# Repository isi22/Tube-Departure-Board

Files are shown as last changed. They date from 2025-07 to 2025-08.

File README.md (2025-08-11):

# 🚇 Tube Departure Board for Raspberry Pi

<!--- Start of badges -->
<!-- Badges: python,raspberrypi,api,3d_printing,electronics,tfl,fusion360 -->

<p align="left">

 
 
 
 
 
 
</p>
<!--- End of badges -->

<!--- Blurb
Recreate the iconic London Underground departure board with a Raspberry Pi! This Python-based application fetches live train data from the Transport for London (TfL) Unified API and displays it in real-time on a compact OLED screen, designed to mimic the classic dot-matrix look.
-->

<!--- Start of Thumbnail-->
<!--- src="Images/thumbnail.png" -->
<!--- End of Thumbnail-->

<div style="text-align:center;">
    <img src="Images/banner.jpg" alt="Miniature Tube Departure Board"">
</div>

Recreate the iconic London Underground departure board with a Raspberry Pi! This Python-based application fetches live train data from the Transport for London (TfL) Unified API and displays it in real-time on a compact OLED screen, designed to mimic the classic dot-matrix look. 

### Table of Contents

**[✨ Features](#-features) <br> 
[📋 Prerequisites](#-prerequisites) <br>
[🔌 Raspberry Pi Setup](#-raspberry-pi-setup) <br>
[🔧 Hardware Assembly and Wiring](#-hardware-assembly-and-wiring) <br>
[💻 Software Installation](#-software-installation) <br>
[🙏 Credits & Inspiration](#-credits--inspiration)**

<br>

## ✨ Features

- **Live London Underground Data:** Fetches real-time Tube arrival predictions for configurable stations and lines.

- **Dot-Matrix Aesthetics:** Utilises a [Dot Matrix Typeface](https://github.com/DanielHartUK/Dot-Matrix-Typeface) to give your display an authentic departure board feel.

- **Compact Display:** Designed for an SSD1322 OLED display on Raspberry Pi.

- **Dual Line Toggle:** Switch between two sets of Tube lines/directions using a physical toggle switch.

- **Smart Power Management:** Includes Raspberry Pi temperature monitoring to prevent overheating.

- **Multi-threaded Architecture:** Uses separate threads for API fetching and display rendering to ensure smooth, responsive updates.

- **Custom 3D-Printed Case:** Design files provided for a miniature Tube departure board enclosure.

## 📋 Prerequisites

To build your London Underground Departure Board, you'll need the following:

- **Raspberry Pi:** Any model capable of running Raspberry Pi OS. I personally used a [Pi Zero WH](https://thepihut.com/products/raspberry-pi-zero-wh-with-pre-soldered-header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).

- **Micro SD card:** For installing the Raspberry Pi OS.

- **Internet Connection:** For the Raspberry Pi to access the TfL API.

- **OLED Display:** An [SSD1322-based OLED display module](https://www.ebay.co.uk/itm/265720175865) connected via SPI.

- **Toggle Switch (Optional but Recommended):** A [mini toggle switch](https://www.amazon.co.uk/dp/B077D9FRGL?ref=ppx_pop_mob_ap_share) connected to a GPIO pin on your Raspberry Pi to switch between the two line configurations (e.g. westbound and eastbound).

- **Transport for London (TfL) API Key:** Tube arrival data is fetched from the [Transport for London Unified API](https://api.tfl.gov.uk/).

- **Access to a 3D printer:** STL files for the custom case, designed to resemble a miniature tube departure board, are provided within this repository.

- **8x [5mmx2mm magnets](https://www.amazon.co.uk/dp/B09H2W3TQZ?ref=ppx_pop_mob_ap_share):** For mounting the miniature departure board.

- **4x M2.6x8mm self tapping screws:** To secure the display and Raspberry Pi to the case.

- **2 x M2.6x6mm self tapping screws:** For closing the case with the back cover.

- **Superglue:** For assembling some of the 3D-printed parts and securing the magnets.

- **Wires and soldering equipment:** For connecting the display and switch to your Raspberry Pi.

## 🔌 Raspberry Pi Setup

These steps prepare your Raspberry Pi's operating system for the project.

### 1. Flash Raspberry Pi OS

- Download the [Raspberry Pi Imager](https://www.raspberrypi.com/software/) for your computer
- Use the Imager to flash Raspberry Pi OS onto your Micro SD card with the following OS customisation settings:
  - **Enable SSH** with password authentication (under the 'Services' tab). This is essential for connecting to your Pi remotely.
  - **Set a username and password.** Make a note of these; you'll need them for SSH access.
  - **Configure wireless LAN.** Add your SSID (Wi-Fi network name) and password.
  - **Set up the locale settings** with the `Europe/London` timezone.
- Insert the prepared SD card into your Raspberry Pi.

### 2. Connect to your Raspberry Pi

- The Raspberry Pi receives its power through its Micro USB Power port. Connect a standard 5V power supply to this port. *Note: On the Pi Zero WH, this is typically the port closest to the end of the board, distinct from any data-only USB ports.*

- Find your Pi's IP address (e.g., from your router's connected devices list) and connect via SSH from your computer:

    ```
    ssh <your_username>@<your_pi_ip_address>
    # Use the username and password you set in the Imager.
    ```

### 3. Enable SPI interface:

For your SSD1322 OLED, you'll need to enable the SPI interface on your Raspberry Pi.

- Open the Raspberry Pi Configuration tool:

    ```
    sudo raspi-config
    ```
- Navigate to `Interface Options` -> `SPI` -> `Yes` to enable it.

- Select `Finish` and reboot your Pi if prompted.

## 🔧 Hardware Assembly and Wiring

This section guides you through preparing the 3D-printed case and connecting your components.

### **1. Wiring:**

The SSD1322 OLED display is wired to the Raspberry Pi by following the comprehensive instructions found in [Chris Crocker-White's UK national rail departure display](https://github.com/chrisys/train-departure-display/blob/main/docs/02-connecting-the-display-to-the-pi.md).

Additionally, a toggle switch has been integrated into this project. This switch enables the display to cycle between different sets of arrival information (for example, distinguishing between eastbound and westbound trains, or various platforms). It is set up in a pull-down configuration, as shown in the provided diagram:

- Connect the centre terminal of the switch to a 3.3V power pin on the Raspberry Pi (e.g., physical pin 17).

- Connect one of the outer terminals of the switch to a Raspberry Pi GPIO pin (e.g. GPIO17, physical pin 11).

- Connect a ~10k Ohm resistor between the Raspberry Pi GPIO pin and a ground pin on the Raspberry Pi. This resistor acts as a pull-down, ensuring the GPIO pin is held low when the switch is open.

      +--------------- (Raspberry Pi 3.3V Power Pin)
      |
      |
      |   +--------------------+
      |   |                    |
      |   |      (Switch)      |
      |   |                    |
      |   +--------------------+
      |             |          |
      |        (Centre Pin) (Outer Pin)
      |             |          |
      +-------------+          |
                               |
                               +------------ Raspberry Pi GPIO Pin
                               |
                               |
                        [ 10kΩ Resistor ]
                               |
                               |
                               | 
                   Raspberry Pi Ground Pin

### **2. 3D Print the Case:**

3D print the [STL files](3D_print_files) provided in this repository. I printed the parts using black PLA filament on an Ender 3 printer.

To give a quick overview, the 3D-printed case consists of the following parts, designed to assemble into a compact and functional departure board:

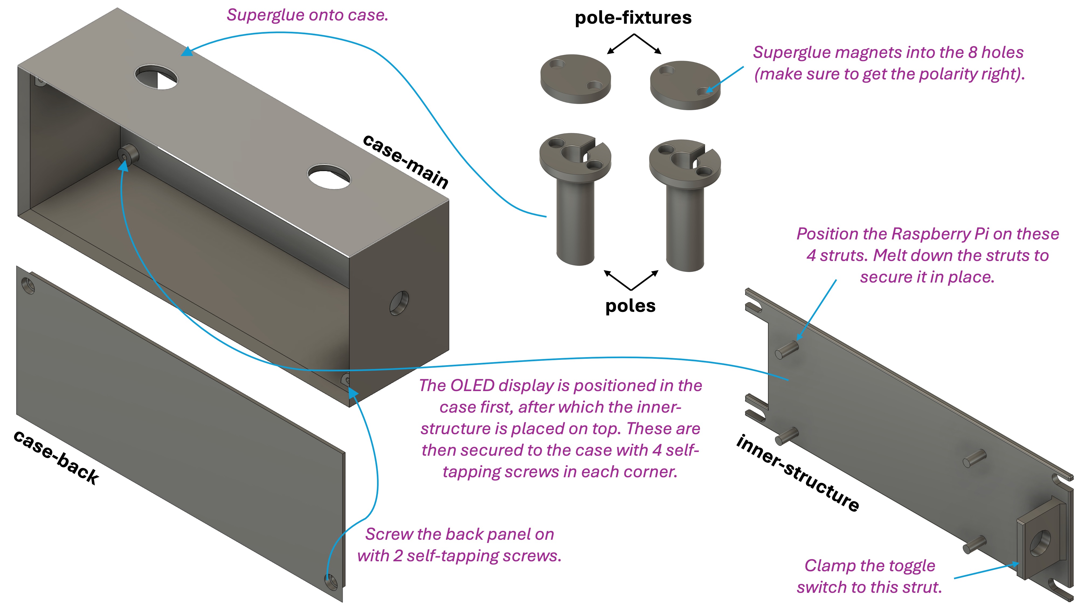
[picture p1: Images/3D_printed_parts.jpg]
3D printed parts illustration


- **Case-main:** The primary rectangular enclosure featuring a cutout at the front for securely fitting the OLED display. Its open rear is designed to be covered by the `case-back` panel.

- **Case-back:** A flat panel that forms the rear closure of the `case-main`, attaching securely with self-tapping screws.

- **Pole (x2):** Two hollow, elliptical posts designed to be superglued to the top of the `case-main`. They align with an elliptical opening on the `case-main`'s top surface, allowing the Raspberry Pi's Micro USB power cable to pass through them. The top of each pole is designed to house two 5mm diameter magnets for mounting the assembled board.

- **Pole-fixture (x2):** Two flat, elliptical parts that are intended to be permanently glued/taped to the desired mounting surface (designed for an overhang). Each `pole-fixture` is designed to hold two 5mm diameter magnets, enabling the departure board's poles to magnetically attach and detach.

- **Internal-structure:** This component fits inside the `case-main`. It features four integrated mounting posts that align with the Raspberry Pi's screw holes, allowing the Pi to be mounted to it. The Pi is secured by heat-staking the posts (gently melting them with a soldering iron), a technique inspired by [Chris Crocker-White's design](https://github.com/chrisys/train-departure-display/blob/main/docs/03-assembling-the-case.md). The `internal-structure` then sits on top of the OLED display, and both are secured into the `case-main` using four self-tapping screws at each corner. It also incorporates a rectangular strut designed for clamping the toggle switch.

### 3. Assemble everything!
Assembly illustration

***Important Pre-Assembly Note:** After securing the switch to the `internal-structure` and placing the Raspberry Pi, it becomes difficult or impossible to insert the Micro SD card. Therefore, ensure you complete the "Flash Raspberry Pi OS" step (Step 1 in the Raspberry Pi Setup section) and insert the prepared SD card into your Raspberry Pi before proceeding with the full assembly steps below.*

Follow these steps to assemble your departure board:

- **Prepare magnets & poles:**
Superglue the 5mm diameter magnets into the designated holes in both the `pole` and `pole-fixture` parts. Ensure you get the polarity right so that the poles on the departure board attract, rather than repel, the magnets in the fixture!
Superglue the `poles` onto the top surface of the `case-main`, aligning them with the elliptical openings.

- **Mount Raspberry Pi & switch:**
Position the Raspberry Pi on the four struts of the `internal-structure` and secure it in place by heat-staking the struts (gently melting them with a soldering iron to secure the Pi's mounting holes). Clamp the toggle switch onto the rectangular strut of the `internal-structure` using the bolt that usually comes with the toggle switch.

- **Position display:**
Carefully position the display over the front opening of the `case-main`.

- **Assemble case with electronics:**
Place the `internal-structure`(with the Raspberry Pi and toggle switch now attached) into the `case-main`, resting it on top of the display. Secure both the display and `internal-structure` to the `case-main` using 4x M2.6x8mm self-tapping screws, one in each corner.

- **Connect Micro USB power:**
Connect the Micro USB cable to your Raspberry Pi's power port, carefully threading it through the hollow pole that aligns with the power port.

- **Final enclosure:**
Arrange all wires neatly inside the case.
Secure the back panel (`case-back`) to the `case-main` with 2x M2.6x6mm self-tapping screws.

## 💻 Software Installation

These steps cover obtaining the project code, installing software dependencies, and configuring the application.

### 1. Clone the GitHub repository:

- From your Raspberry Pi's terminal, navigate to where you want to store the project (e.g., your home directory `cd ~`) and clone the repository:

    ```
    cd ~
    git clone https://github.com/isi22/Tube-Departure-Board
    cd Tube-Departure-Board
    ```

### 2. Create a python virtual environment:
Using a virtual environment is best practice for managing project dependencies.

```
python3 -m venv .venv
source .venv/bin/activate
```

### 3. Install system and python dependencies:
Install system dependencies (for fonts and display drivers and all required Python packages from the `requirements.txt`.

```
sudo apt-get install -y python3-dev libjpeg-dev zlib1g-dev libfreetype6-dev liblcms2-dev libopenjp2-7 build-essential pkg-config

pip install -r requirements.txt
```

### 4. Configure the project settings:

Update the `config.py` file with your project-specific configurations. This is where you define your station, the lines to monitor, and settings for your OLED and optional GPIO switch.

- Open the file:
    ```
    nano src/config.py
    ```

- Once `nano` opens, you will see the contents of `config.py`. Use the arrow keys to move the cursor up, down, left, and right. Type directly to make your changes.

- Save and Exit (`Ctrl + X`).

### 5. Set up the main script as a systemd service:

To ensure the departure board starts automatically when your Raspberry Pi boots and runs reliably in the background, set it up as a systemd service.

- Create a systemd service file:
    ```
    sudo nano /etc/systemd/system/tube-departure-board.service
    ```

- Add the following content to the file. Replace `<your_username>` and `<your_api_key>` with your actual username and API credentials. The TfL API Key (referred to as primary key) can be found in your [Profile](https://api-portal.tfl.gov.uk/profile) in the TfL API portal after registering and subscribing to the `500 Requests per min` product.

    ```
    [Unit]
    Description=London Underground Departure Board Service
    After=network.target

    [Service]
    User=<your_username>
    WorkingDirectory=/home/<your_username>/Tube-Departure-Board
    ExecStart=/home/<your_username>/Tube-Departure-Board/.venv/bin/python /home/<your_username>/Tube-Departure-Board/src/main.py
    Restart=on-failure
    StandardOutput=journal
    StandardError=journal
    Environment = "TFL_API_KEY=<your_api_key>"
    
    [Install]
    WantedBy=multi-user.target
    ```

- Save and exit (Ctrl+O, Enter, Ctrl+X in nano).

- Reload systemd, enable, and start the service:

    ```
    sudo systemctl daemon-reload
    sudo systemctl enable tube-departure-board.service
    sudo systemctl start tube-departure-board.service
    ```

- Check the service status and logs:

    ```
    sudo systemctl status tube-departure-board.service
    journalctl -u tube-departure-board.service -f # For live service logs
    ```

- Confirm that the service is active (running).

## 🙏 Credits & Inspiration

This project draws inspiration and direct resources from the following:

- **Dot Matrix Typeface:** The authentic visual style is achieved using [Daniel Hart's](https://github.com/DanielHartUK/Dot-Matrix-Typeface) excellent Dot Matrix Typeface.

- **Core Code & Logic:** Both [Chris Crocker-White's](https://github.com/chrisys/train-departure-display) UK National Rail Departure Display and [Sean Petykowski's](https://github.com/petykowski/London-TFL-Arrivals-Board) London TfL Arrivals Board served as direct inspiration and a foundational basis for the Python code and API interaction logic implemented in this project.

- **Hardware Design, Assembly & 3D Printed Parts:**
[Chris Crocker-White's](https://github.com/chrisys/train-departure-display) comprehensive documentation for his UK National Rail Departure Display was particularly instrumental for the hardware design, assembly techniques (such as heat-staking the Raspberry Pi into the case), and provided significant inspiration for the custom 3D-printed enclosure parts. His detailed wiring guide for the display was also followed.

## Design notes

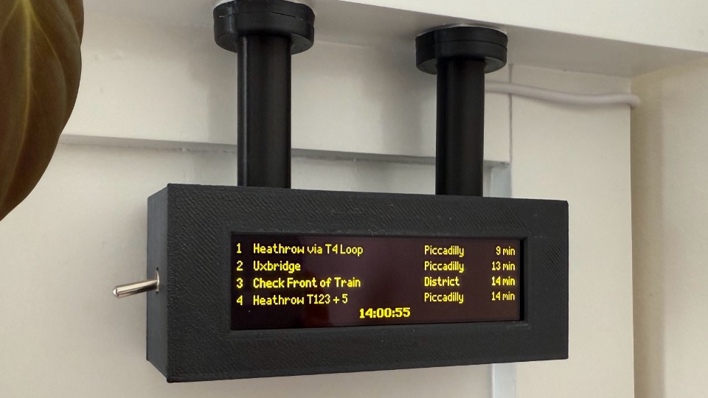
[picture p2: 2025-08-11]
Images/thumbnail.png

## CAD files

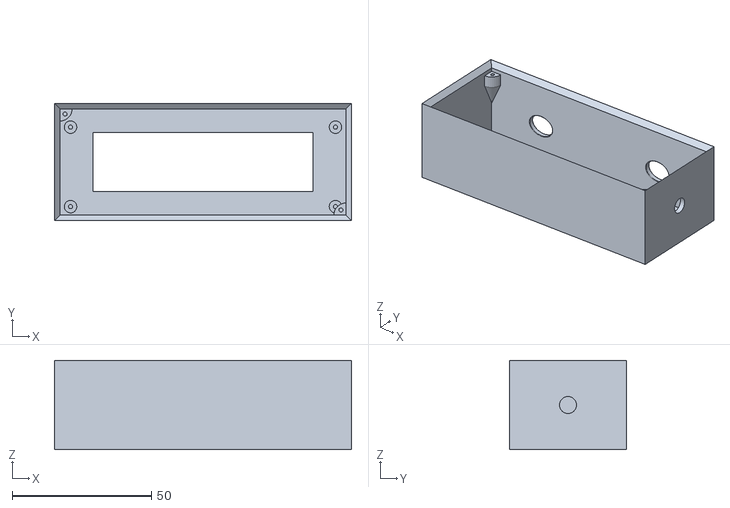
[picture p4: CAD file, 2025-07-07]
3D_print_files/case-main.stl
106.5 x 42.0 x 32.0

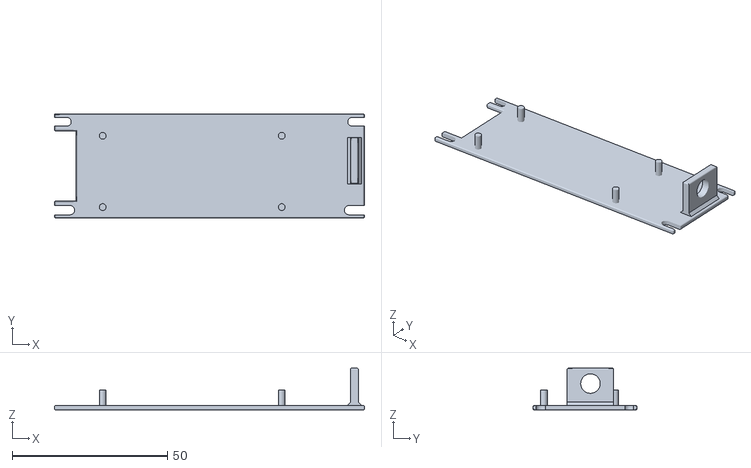
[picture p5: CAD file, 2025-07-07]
3D_print_files/internal-structure.stl
100.0 x 33.5 x 13.5

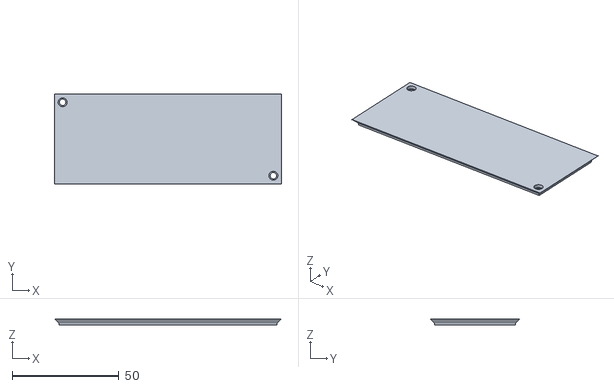
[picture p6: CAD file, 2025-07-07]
3D_print_files/case-back.stl
106.5 x 42.0 x 3.00

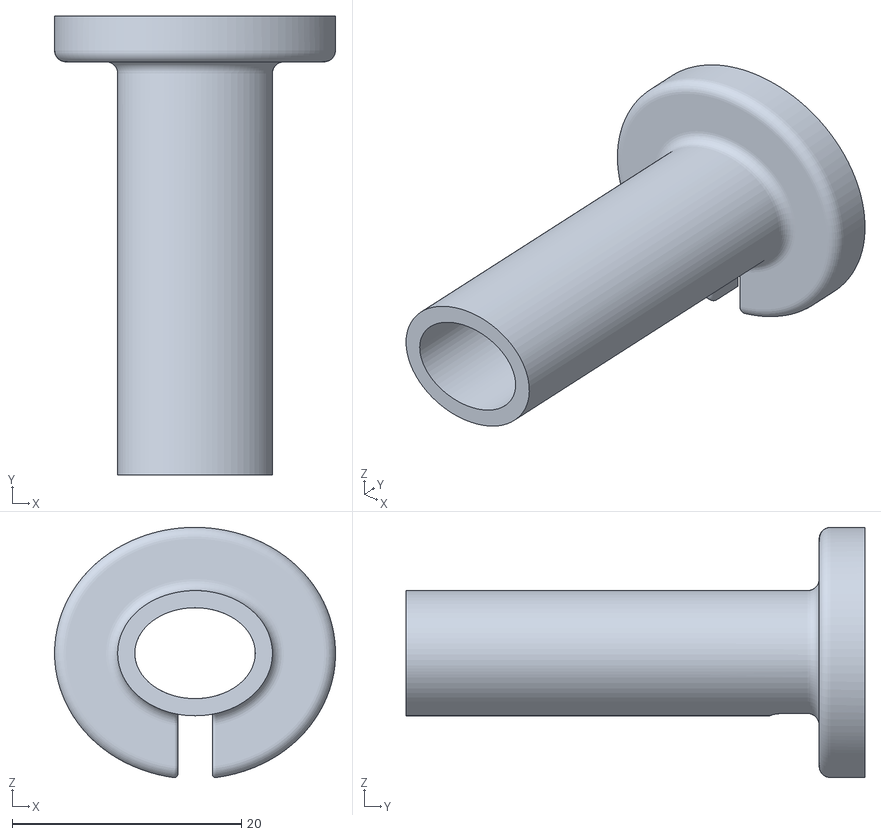
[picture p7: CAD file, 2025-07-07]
3D_print_files/pole.stl
24.5 x 40.0 x 21.8

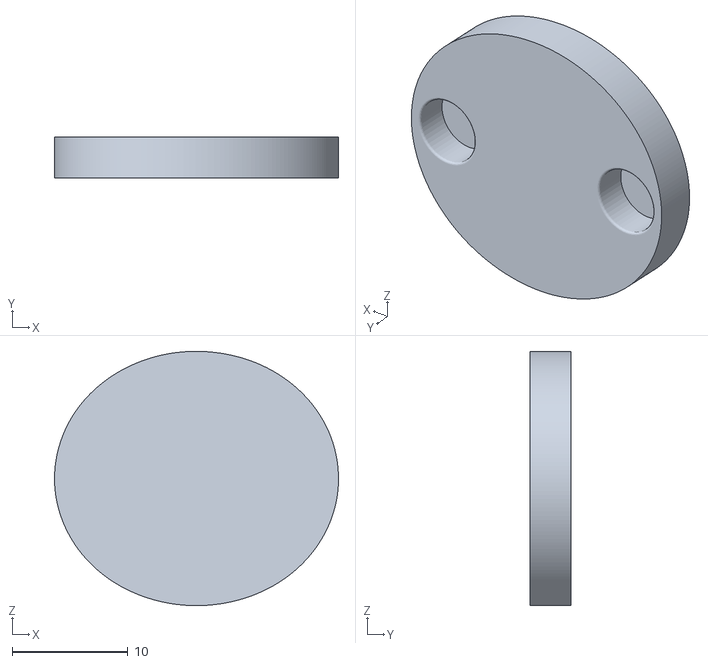
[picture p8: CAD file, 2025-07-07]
3D_print_files/pole_fixture.stl
24.5 x 3.50 x 21.9

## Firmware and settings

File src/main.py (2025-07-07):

# --- IMPORTS ---
import config
import os
import time
import sys
import requests
import json
from datetime import datetime
import math
import pytz
import threading
import queue

from PIL import ImageFont, ImageDraw, Image
from luma.core.render import canvas


# --- CONDITIONAL DISPLAY DRIVER / EMULATOR SETUP ---
IS_RASPBERRY_PI = False
if sys.platform.startswith("linux") and os.uname().machine.startswith("arm"):
    try:
        from luma.core.interface.serial import spi
        from luma.oled.device import ssd1322
        import RPi.GPIO as GPIO

        IS_RASPBERRY_PI = True
    except ImportError:
        print(
            "Warning: Running on Raspberry Pi but luma.oled drivers not found. Falling back to emulator."
        )
if not IS_RASPBERRY_PI:
    from luma.emulator.device import pygame


# --- GLOBAL FONT DEFINITIONS ---
font: ImageFont.FreeTypeFont = None
fontBold: ImageFont.FreeTypeFont = None

# --- GLOBAL API SESSION & QUEUES FOR THREAD COMMUNICATION ---
API_SESSION = requests.Session()
raw_api_data_queue1 = queue.Queue(maxsize=1)
raw_api_data_queue2 = queue.Queue(maxsize=1)
# rendered_frames_queue = queue.Queue(maxsize=1)
rendered_frames_queue1 = queue.Queue(maxsize=1)
rendered_frames_queue2 = queue.Queue(maxsize=1)

# --- GLOBAL BUFFER FOR FINAL DISPLAY OUTPUT ---
display_output_buffer: Image.Image = None

# --- GLOBAL DISPLAY DEVICE ---
display_device = None  # Initialize display_device to None

# --- GLOBAL DEFINITION OF ARRIVALS AREA AND CLOCK AREA OF DISPLAY ---
arrivals_display_rect, clock_display_rect = None, None  # Initialize display rectangles

# --- HELPER FUNCTIONS ---


def make_Font(name: str, size: int) -> ImageFont.FreeTypeFont:
    font_path = os.path.abspath(os.path.join(os.path.dirname(__file__), "fonts", name))
    try:
        return ImageFont.truetype(font_path, size, layout_engine=ImageFont.Layout.BASIC)
    except IOError:
        print(
            f"Error: Could not load font from {font_path}. Using default system font."
        )
        return ImageFont.load_default()


def initialize_fonts():
    global font, fontBold
    font = make_Font("Dot Matrix Regular.ttf", config.fontSize)
    fontBold = make_Font("Dot Matrix Bold.ttf", config.fontSize)


def get_time_to_arrival(arrival, font):
    """Calculates the time to arrival and formats it for display."""

    seconds_to_arrival = int(arrival["arrival_time"].timestamp() - time.time())
    time_to_arrival = " "  # Default value if not displayed
    time_width = 0  # Default value if not displayed

    if seconds_to_arrival >= config.earliest_arrival * 60:
        display_check = True
        minutes_to_arrival = seconds_to_arrival / 60
        # print(minutes_to_arrival)

        # Format the time string
        if minutes_to_arrival > 1:
            time_to_arrival = (
                f"{math.floor(minutes_to_arrival + 0.5)} min"
                # + "   "
                # + str(arrival["arrival_time"])
            )
        else:
            time_to_arrival = "due"  # + "   " + str(arrival["arrival_time"])

        bbox = font.getbbox(time_to_arrival)
        time_width = bbox[2] - bbox[0]

    else:
        display_check = False
    return time_to_arrival, time_width, display_check


# --- API INTERACTION FUNCTIONS ---


def query_TFL(
    url: str,
    params: dict = None,
    max_retries: int = 3,
    _session: requests.Session = None,
) -> list:
    session_to_use = _session if _session else requests.Session()
    for retry_attempt in range(max_retries):
        try:
            response = session_to_use.get(url, params=params, timeout=10)
            response.raise_for_status()
            json_response = response.json()
            return json_response if json_response else []
        except (requests.exceptions.RequestException, json.JSONDecodeError) as e:
            print(
                f"Error calling TfL API (Attempt {retry_attempt + 1}/{max_retries}): {e}"
            )
            if retry_attempt == max_retries - 1:
                raise RuntimeError(
                    f"Failed to fetch data from {url} after {max_retries} retries: {e}"
                )
        time.sleep(1)
    return []


def get_station_id(
    _session: requests.Session = None,
    lines_filter1: set = None,
    lines_filter2: set = None,
) -> dict:

    TFL_STOPPOINT_SEARCH_URL = "https://api.tfl.gov.uk/StopPoint/Search"
    TFL_STOPPOINT_DETAIL_URL_BASE = (
        "https://api.tfl.gov.uk/StopPoint/"  # Base URL for detail/children
    )

    # 1. Search for the station ---
    params_search = {
        "query": config.station,
        # "modes": "tube",
        "maxResults": 1,
        "app_key": config.api_key,
    }
    search_response = query_TFL(
        TFL_STOPPOINT_SEARCH_URL, params_search, _session=_session
    )

    if (
        not search_response
        or not search_response.get("matches")
        or len(search_response["matches"]) == 0
    ):
        raise RuntimeError(
            f"The following station could not be found: {config.station}."
        )

    search_result_id = search_response["matches"][0]["id"]

    # 2. Get details (including children) for the found StopPoint
    params_detail = {
        "app_key": config.api_key,
    }
    # Construct the full URL using the search_result_id
    detail_response = query_TFL(
        TFL_STOPPOINT_DETAIL_URL_BASE + search_result_id,
        params_detail,
        _session=_session,
    )

    if not detail_response:
        raise RuntimeError(
            f"Could not retrieve details for station ID: {search_result_id}"
        )

    final_station_data = None

    # 3. Determine if the main StopPoint or one of its children matches ---
    # Check the primary StopPoint itself
    # print(detail_response)
    if detail_response.get("stopType") == "NaptanMetroStation" and check_lines(
        detail_response.get("lines", []), lines_filter1, lines_filter2
    ):
        final_station_data = detail_response
    elif detail_response.get(
        "children"
    ):  # If it has children (likely a TransportInterchange)
        for child in detail_response["children"]:
            if child.get("stopType") == "NaptanMetroStation" and check_lines(
                child.get("lines", []), lines_filter1, lines_filter2
            ):
                final_station_data = child  # Assign the child that matched!
                break  # Found a matching child, no need to check others

    # 4. Return or raise error based on finding a match ---
    if final_station_data:
        return {
            "name": final_station_data.get("commonName"),
            "id": final_station_data.get("id"),
        }
    else:
        raise RuntimeError(
            f"'The following station is not served by the specified tube lines or is not a valid MetroStation: {config.station}."
        )


def check_lines(lines, lines_filter1, lines_filter2):
    served_lines = set()
    for line_info in lines:
        served_lines.add(line_info["id"])

    # Extract the line names specified by the user from the filter sets
    extracted_lines_filter1 = {line_name for line_name, _ in lines_filter1}
    extracted_lines_filter2 = {line_name for line_name, _ in lines_filter2}

    # Combine all unique line names from both filter sets
    all_filtered_lines_to_check = extracted_lines_filter1.union(extracted_lines_filter2)

    # Check if all lines in 'all_filtered_lines_to_check' are present in 'served_lines'
    return all_filtered_lines_to_check.issubset(served_lines)


def get_lines_filter(lines_config_list: list, _session: requests.Session = None) -> set:
    TFL_LINE_SEARCH_URL = "https://api.tfl.gov.uk/Line/Search/"
    filter_set = set()
    params = {
        "app_key": config.api_key,
    }
    for entry in lines_config_list:

        search_response = query_TFL(
            TFL_LINE_SEARCH_URL + entry.get("line"),
            params,
            _session=_session,
        )

        if not search_response.get("searchMatches"):
            raise RuntimeError(
                f"The following tube line could not be found: {entry.get('line')}."
            )

        line = search_response["searchMatches"][0]["lineId"]
        direction_substring = entry.get("direction")
        if line and direction_substring:
            filter_set.add((line.lower(), direction_substring.lower()))
    return filter_set


def get_arrivals(
    station: dict,
    filter_criteria_set: set,
    n: int = 7,
    _session: requests.Session = None,
) -> list:
    try:
        TFL_STOPPOINT_ARRIVALS_URL = (
            "https://api.tfl.gov.uk/StopPoint/" + station["id"] + "/Arrivals"
        )
        # TFL_STOPPOINT_ARRIVALS_URL = (
        #     "https://api.tfl.gov.uk/Line/district/Arrivals/" + station["id"]
        # )

        params = {
            "app_key": config.api_key,
        }
        # print(params)
        all_arrivals = query_TFL(TFL_STOPPOINT_ARRIVALS_URL, params, _session=_session)
        # print(json.dumps(all_arrivals, indent=2))
        if not isinstance(all_arrivals, list):
            return []
        filtered_predictions = [
            p
            for p in all_arrivals
            if (
                (p_line := p.get("lineId", "").lower())
                and (p_platform := p.get("platformName", "").lower())
                and p.get("timeToStation", float("inf")) >= config.earliest_arrival * 60
                and any(
                    f_line == p_line and f_direction_substring in p_platform
                    for f_line, f_direction_substring in filter_criteria_set
                )
            )
        ]
        filtered_sorted_arrivals = sorted(
            filtered_predictions, key=lambda p: p.get("timeToStation", math.inf)
        )
        final_display_info = []
        for arrival in filtered_sorted_arrivals[:n]:
            destination = arrival.get("towards") or arrival.get("destinationName")
            destination = destination if destination else "Unknown Destination"
            expected_arrival_utc_str = arrival.get("expectedArrival")
            arrival_dt = None
            if expected_arrival_utc_str:
                try:
                    naive_dt = datetime.strptime(
                        expected_arrival_utc_str, "%Y-%m-%dT%H:%M:%SZ"
                    )
                    arrival_dt = naive_dt.replace(tzinfo=pytz.utc)
                except ValueError:
                    print(
                        f"Warning: Could not parse expectedArrival: {expected_arrival_utc_str}"
                    )
            if arrival_dt is not None:
                final_display_info.append(
                    {
                        "destination": destination,
                        "arrival_time": arrival_dt,
                        "timeToStation": arrival.get("timeToStation"),
                        "lineName": arrival.get("lineName"),
                    }
                )
        return final_display_info
    except Exception as e:
        print(f"An unexpected error occurred in get_arrivals: {e}")
        return []


# --- DISPLAY DRAWING FUNCTIONS ---
# These functions draw content onto a 'draw_obj' (PIL.ImageDraw.Draw) directly,
# which is typically the off-screen buffer of the Render Worker thread.


def draw_centered_text_rows(
    draw_obj: ImageDraw.ImageDraw,
    rows_text: list[str],
    font: ImageFont.FreeTypeFont,
):
    """Draws multiple lines of text, centered horizontally and stacked vertically, onto the given draw object."""
    row_dimensions = []
    total_text_height = 0
    for row_content in rows_text:
        bbox = font.getbbox(row_content)
        width = bbox[2] - bbox[0]
        height = bbox[3] - bbox[1]
        row_dimensions.append(
            {"content": row_content, "width": width, "height": height}
        )
        total_text_height += height
    total_height_with_spacing = (
        total_text_height
        + (len(rows_text) - 1) * config.display_settings["row_padding"]
    )
    start_y_offset = (display_device.height - total_text_height) / 2
    current_y = start_y_offset
    for row_data in row_dimensions:
        row_content = row_data["content"]
        row_width = row_data["width"]
        row_height = row_data["height"]
        x_offset = (display_device.width - row_width) / 2
        draw_obj.text((x_offset, current_y), text=row_content, font=font, fill="yellow")
        current_y += row_height + config.display_settings["row_padding"]


def draw_initial_display(station_info: dict):
    """
    Draws the initial welcome screen as a full screen update.
    This clears the entire display via luma's canvas.
    """
    with canvas(display_device) as draw_obj:  # This clears the whole display
        draw_centered_text_rows(
            draw_obj,
            ["Welcome to", station_info["name"]],
            fontBold,
        )


def draw_pause_display(temp: float):
    """
    Draws a display indicating that the pi is pausing until the
    temperature has dropped back below the safe threshold.
    """
    with canvas(display_device) as draw_obj:  # This clears the whole display
        draw_centered_text_rows(
            draw_obj,
            [
                "Raspberry Pi temperature is " + f"{temp:.1f}" + " C.",
                "Waiting for temperature to drop below "
                + str(config.max_pi_temp - 3)
                + " C.",
            ],
            font,
        )


def draw_clock(
    draw_obj: ImageDraw.ImageDraw,
    font: ImageFont.FreeTypeFont,
):
    """
    Draws the live clock at the bottom of the display onto the given draw object.
    It's responsible for drawing the text, but not for clearing or display update.
    """
    # Clear the entire clock display area on the buffer to black
    draw_obj.rectangle(
        clock_display_rect,
        fill="black",
    )

    clock_str = datetime.now(pytz.timezone("Europe/London")).strftime("%H:%M:%S")

    draw_obj.text(
        (clock_display_rect[0], clock_display_rect[1]),
        text=clock_str,
        font=font,
        fill="yellow",
    )


def draw_arrival_lines(
    draw_obj: ImageDraw.ImageDraw,
    arrivals: list,
    font: ImageFont.FreeTypeFont,
):
    """
    Draws the list of arrival predictions on the main board area onto the global buffer.
    It clears the entire arrivals area on the buffer before redrawing.
    """

    # Clear the entire arrivals display area on the buffer to black
    draw_obj.rectangle(
        arrivals_display_rect,
        fill="black",
    )

    max_y_for_arrivals = arrivals_display_rect[3]

    row_num = 1

    for arrival in arrivals:
        time_to_arrival, time_width, display_check = get_time_to_arrival(arrival, font)

        if display_check:
            ypos = (row_num - 1) * (
                config.fontSize + config.display_settings["row_padding"]
            ) + config.display_settings["yoffset"]

            if ypos >= max_y_for_arrivals:
                break

            draw_obj.text(
                (config.display_settings["xoffset"], ypos),
                text=str(row_num),
                font=font,
                fill="yellow",
            )
            draw_obj.text(
                (
                    config.display_settings["xoffset"]
                    + config.display_settings["space_arrival_num_dest_name"],
                    ypos,
                ),
                text=arrival["destination"],
                font=font,
                fill="yellow",
            )

            if len(config.lines1) > 1:
                # If multiple lines are configured, display the line name
                # at the end of the row.
                draw_obj.text(
                    (
                        config.display_settings["xoffset_line_name"],
                        ypos,
                    ),
                    text=arrival["lineName"],
                    font=font,
                    fill="yellow",
                )

            draw_obj.text(
                (
                    display_device.width
                    - time_width
                    - config.display_settings["xoffset"],
                    ypos,
                ),
                text=time_to_arrival,
                font=font,
                fill="yellow",
            )
            row_num += 1


# --- BACKGROUND WORKER THREAD FUNCTIONS ---
# These threads run in the background, performing API fetches and rendering.


def api_fetch_worker(
    station_info: dict,
    lines_filter1: set,
    lines_filter2: set,
    pause_event: threading.Event,
):
    """
    Fetches raw API data periodically and puts it into raw_api_data_queue.
    This thread performs Task 3: fetching new API data every 30 seconds.
    """
    while True:
        pause_event.wait()  # Blocks until pause_event is set
        try:
            print(
                f"DEBUG API Fetch Worker: Fetching new raw API data at {datetime.now().strftime('%H:%M:%S')}..."
            )

            new_arrivals1 = get_arrivals(
                station_info,
                lines_filter1,
                _session=API_SESSION,
            )

            new_arrivals2 = get_arrivals(
                station_info,
                lines_filter2,
                _session=API_SESSION,
            )

            try:
                # Clear any old data in queue, ensuring only the latest is available
                while not raw_api_data_queue1.empty():
                    raw_api_data_queue1.get_nowait()
                raw_api_data_queue1.put_nowait(new_arrivals1)

                while not raw_api_data_queue2.empty():
                    raw_api_data_queue2.get_nowait()
                raw_api_data_queue2.put_nowait(new_arrivals2)

                print(
                    "DEBUG API Fetch Worker: New raw API data successfully put into queue."
                )
            except queue.Full:
                print(
                    "WARNING API Fetch Worker: Raw API data queue was full, render worker too slow. Data dropped."
                )

        except Exception as e:
            print(
                f"ERROR API Fetch Worker: Data fetch failed: {e}. Retrying after sleep."
            )

        time.sleep(config.refresh_interval_TFL)


def arrival_lines_worker(pause_event: threading.Event):
    """
    This thread is responsible for drawing all display elements onto an off-screen buffer.
    It takes raw API data from the API fetcher and renders full frames (clock + arrivals),
    then puts completed frames into rendered_frames_queue for the main thread.
    This thread handles Task 2 (drawing arrivals at 1 FPS) and preparing clock updates (part of Task 1).
    """

    # Private buffer and drawing handle for this worker thread
    # render_buffer = Image.new(display_device.mode, display_device.size)
    # render_draw_handle = ImageDraw.Draw(render_buffer)
    render_buffer1 = Image.new(display_device.mode, display_device.size)
    render_draw_handle1 = ImageDraw.Draw(render_buffer1)
    render_buffer2 = Image.new(display_device.mode, display_device.size)
    render_draw_handle2 = ImageDraw.Draw(render_buffer2)

    # Variables for state of arrivals data consumed from API Fetch Worker
    current_arrivals1 = []
    current_arrivals2 = []

    # Timing for rendering arrivals (Task 2: e.g., 0.5 FPS)
    arrivals_render_interval = config.refresh_interval_display

    while True:

        pause_event.wait()  # Blocks until pause_event is set

        loop_start_time = time.monotonic()

        # --- Get latest raw API data (non-blocking) ---
        try:
            current_arrivals1 = raw_api_data_queue1.get_nowait()
            current_arrivals2 = raw_api_data_queue2.get_nowait()
            print("DEBUG Render Worker: Consumed new raw API data from queue.")
        except queue.Empty:
            pass  # No new raw API data, use existing

        # --- Draw Arrival Lines  ---

        draw_arrival_lines(
            render_draw_handle1,
            current_arrivals1,
            font=font,
        )

        draw_arrival_lines(
            render_draw_handle2,
            current_arrivals2,
            font=font,
        )

        # --- Put the completed frame COPY into the output queue for the main thread ---
        try:
            while not rendered_frames_queue1.empty():
                rendered_frames_queue1.get_nowait()
            rendered_frames_queue1.put_nowait(render_buffer1.copy())
            while not rendered_frames_queue2.empty():
                rendered_frames_queue2.get_nowait()
            rendered_frames_queue2.put_nowait(
                render_buffer2.copy()
            )  # Put a COPY to avoid race conditions

            print(
                f"DEBUG Render Worker: display with updated arrival lines put into queue."
            )
        except queue.Full:
            print(
                "WARNING Render Worker: Rendered frames queue was full, main thread too slow to consume."
            )

        # Sleep to control render worker's own FPS
        render_duration = time.monotonic() - loop_start_time
        sleep_time = arrivals_render_interval - render_duration
        if sleep_time > 0:
            time.sleep(sleep_time)
        else:
            print(
                f"WARNING Render Worker: Took too long ({render_duration:.3f}s) for {arrivals_render_interval:.3f}s budget."
            )
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

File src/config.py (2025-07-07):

import os

# --- General Configuration ---

station = "South Kensington"  # The London Underground station to display on the board.
earliest_arrival = 10  # Minimum arrival time (in minutes) for a train to be displayed.
                      # For example, if you need 10 minutes to walk to the station, setting this to 10
                      # will ensure only trains you might realistically catch are shown.

lines1 = [
    {"line": "Piccadilly", "direction": "eastbound"},
    {"line": "District", "direction": "eastbound"},
]  # Primary set of Tube lines and their specific directions to monitor.
   # Valid directions include: "eastbound", "westbound", "northbound", "southbound".
   # For DLR services, use platform for direction (e.g., {"direction": "platform 1"}).

lines2 = [
    {"line": "Piccadilly", "direction": "westbound"},
    {"line": "District", "direction": "westbound"},
]  # Second set of Tube lines and directions.
   # The physical toggle switch on the hardware will cycle the display between lines1 and lines2.

displayRotation = 0  # Rotation of the OLED display content.
                     # 0: No rotation (default orientation)
                     # 1: 90° clockwise rotation
                     # 2: 180° rotation
                     # 3: 270° clockwise rotation

switch_GPIO_pin = 17 # BCM (Broadcom pin numbering) GPIO pin connected to the toggle switch.
                     # Change this value to match your switch's connection.

refresh_interval_TFL = 20  # Interval (in seconds) between API requests to TFL for new data.
refresh_interval_display = 3  # Interval (in seconds) for refreshing the visual content on the OLED display.

max_pi_temp = 60  # Maximum Raspberry Pi CPU temperature (in Celsius) allowed.
                  # If the temperature exceeds this, the display will pause refreshing
                  # until the CPU has cooled down to prevent overheating.


# --- API Key Configuration ---
# Your TfL App Key is retrieved from an environment variable for enhanced security.
# Ensure 'TFL_API_KEY' is set in your system's environment
# (e.g., in your systemd service file).
api_key = os.getenv("TFL_API_KEY")


# --- Display Layout Settings ---
display_settings = {
    "xoffset": 3,  # Horizontal padding (in pixels) from the left and right edges of the display.
    "yoffset": 3,  # Vertical padding (in pixels) from the top and bottom edges of the display.
    "row_padding": 3,  # Vertical spacing (in pixels) between individual rows of arrival information.
    "space_arrival_num_dest_name": 13,  # Horizontal space (in pixels) between the arrival number and the destination name.
    "space_line_name_arrival_time": 25,  # Horizontal space (in pixels) between the line name and the arrival time.
}

fontSize = 10  # Base font size (in pixels) for the display text.
               # 10 is generally a good size for 128x64 OLED displays to fit multiple lines.
